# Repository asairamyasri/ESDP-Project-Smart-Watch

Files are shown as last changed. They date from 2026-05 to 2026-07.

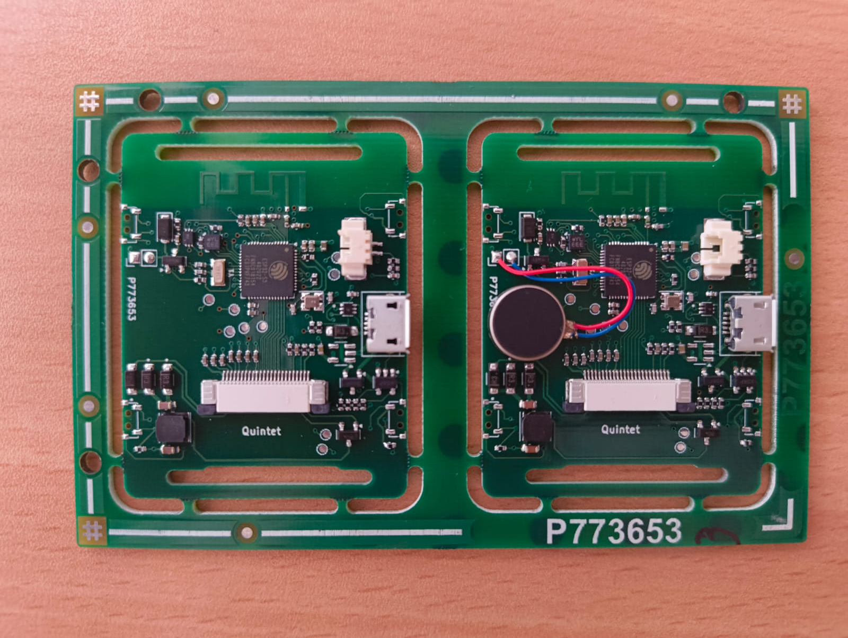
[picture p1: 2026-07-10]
Images/Fabricated_PCB.jpeg

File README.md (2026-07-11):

# Ultra-Low-Power ESP32 Smartwatch

## Overview
This project is an ESP32-based smartwatch using an E-Ink display for low-power wearable applications. 

## Features
- ESP32 microcontroller
- E-Ink display
- Low-power operation
- Real-time clock support
- Custom watch faces
- Battery-powered wearable system

## Team Members
- A Sai Ramya Sri (EE24BTECH11202)
- JLB Saraswathi (EE24BTECH11209)
- K Lakshmi Pranavi (EE24BTECH11210)
- Lakshitha Totakura (EE24BTECH11214)
- P Devi Amrutha (EE24BTECH11219)
## Project Structure
proposal/
bom/
hardware design/
software code/
current status/

## Hardware
The hardware section includes:
- Schematic design
- PCB layout
- Gerber files

## Software
The software section contains:
-GPIO Mapping: Hardware configuration for the ESP32-S3.
-Hardware tests: Firmware for component testing and bring-up.
-Driver Logic: Low-power E-Ink and battery management.
## Current Status

- [x] Create a Proposal
- [x] Prepare the BOM
- [x] Draw the schematic
- [x] PCB Layout
- [x] Generate Gerber Files
- [x] Order PCB on PCB Power
- [x] Design a case for the PCB
- [x] Develop Firmware
- [x] Receive PCB
- [ ] Firmware Integration
- [ ] Hardware Debugging if any

## Ongoing Work
Testing firmware on the PCB.

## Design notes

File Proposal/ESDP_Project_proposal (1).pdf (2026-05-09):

# Ultra-Low-Power ESP32 Smartwatch Project Proposal

### EE24BTECH11202 - Annapureddy Sai Ramyasri EE24BTECH11209 - J Laxmi Bhavani Saraswathi EE24BTECH11210 - Karri Lakshmi Pranavi EE24BTECH11214 - Lakshitha Totakura EE24BTECH11219 - Pothuri Devi Amrutha

### 1 Application / Problem Statement

With the rapid growth of wearable technology, smartwatches have become an essential tool for timekeeping, fitness tracking, and connectivity. However, most commercially available smartwatches suffer from a critical limitation: poor battery life. Frequent charging (often daily) significantly reduces usability and user convenience. Additionally, many smartwatches rely on power-hungry displays and continuously active wireless modules, making them inefficient for basic use cases such as timekeeping, alarms, and lightweight health monitoring.
There is a clear need for a low-power, cost-effective smartwatch that:
- Provides essential features like time display, stopwatch, and notifications
- Maximizes battery life (multi-day operation)
- Maintains readability in all lighting conditions
- Allows modular expansion for health monitoring

### 2 Proposed Solution

To address the above challenges, we propose the design and development of an Ultra-Low-Power Smartwatch based on the ESP32-S3 microcontroller.

### Core Architecture

The system is built around the ESP32-S3 dual-core microcontroller, which provides integrated Wi-Fi and Bluetooth Low Energy (BLE) capabilities for future wireless

synchronization and updates.

### Display System

A 1.54-inch E-Ink (GDEY0154D67) display with 200×200 resolution is used. Unlike traditional LCD/OLED displays, E-Ink:

- Consumes power only during refresh cycles
- Offers good sunlight readability
- Enables an always-on display with minimal power usage

### SPI Communication Interface

The communication between the ESP32-S3 and the E-Ink display is implemented using the Serial Peripheral Interface (SPI) protocol. The ESP32 acts as the master, while

the display functions as the slave device.
SPI enables fast and efficient transfer of command and display data using signals such as MOSI, SCLK, CS, and DC. Additional control lines like RST and BUSY ensure proper synchronization during display updates.
This interface is chosen for its high speed, low pin requirement, and suitability for display communication.

### User Interface

The smartwatch uses a non-touch physical interface consisting of four push buttons for navigation. A vibration motor is integrated to provide haptic feedback for alerts and user interactions.

### Power Management System

- Powered by a 3.7V Li-Po battery (200–500 mAh)
- Uses a low-dropout (LDO) regulator (NCP167AMX330TBG) to generate

stable 3.3V and 1.8V rails

- Includes a battery charging IC with constant-current (CC) and constant-voltage

(CV) charging

- Protection circuitry ensures safety against over-voltage, short-circuits, and deep

discharge

### Ultra-Low-Power Optimization

The ESP32 operates in deep sleep mode, reducing standby current to approximately 10–150 µA. The system wakes up only when necessary using:

- Button interrupts
- Motion detection via accelerometer

### Sensor Integration

- BMA423 Accelerometer: Used for motion detection, step counting, and wake-up

triggering

### Future Expansion

The I2C architecture allows easy integration of sensors like:

- MAX30102: Heart rate and SpO2 monitoring

### Debugging and Connectivity

A CP2102N/CP2104 USB-UART bridge is used for:

- Firmware uploading
- Serial debugging

An ESD protection circuit is included to safeguard the system from electrostatic discharge on USB lines.

### 3 Practical Feasibility and Cost Effectiveness

### Component Availability

All components used in the design are:

- Commercially available through distributors such as Digi-Key, Robu, Amazon.
- Widely used in embedded and IoT applications
- Supported by strong documentation and community resources

Key components such as ESP32-S3, E-Ink display modules, Li-Po batteries, and sensor ICs are readily accessible, ensuring smooth procurement and development.

### Cost Effectiveness

The design is optimized for affordability while maintaining performance. Key cost considerations:

- ESP32-S3 provides multiple functionalities (MCU + wireless), reducing component

count

- E-Ink display reduces long-term energy cost and battery size requirements
- Use of standard passive components and widely available ICs minimizes BOM cost

Based on the provided Bill of Materials (BOM), the estimated prototype cost remains

within a reasonable budget for academic and small-scale production purposes.

### Power Efficiency Advantage

The major advantage of this design is its extended battery life of 5–7 days, achieved through:

- Low-power display technology
- Deep sleep optimization
- Event-driven system wake-up

This makes the device significantly more efficient compared to conventional smartwatches.

### Implementation Feasibility

The project is highly feasible due to:

- Modular design architecture
- Availability of development tools for ESP32
- Simple PCB design with standard interfaces (I2C, UART, GPIO)

The system can be implemented, tested, and iteratively improved within a typical academic project timeline.
Total Component Cost : Rs.3,000
PCB Fabrication and Assembly : Rs.7,000 Total price : Rs.10,000

### 4 Conclusion

The proposed ultra-low-power smartwatch provides a practical and efficient solution to the limitations of existing wearable devices. By combining energy-efficient hardware, optimized power management, and scalable architecture, the design achieves a balance between functionality, cost, and battery life.

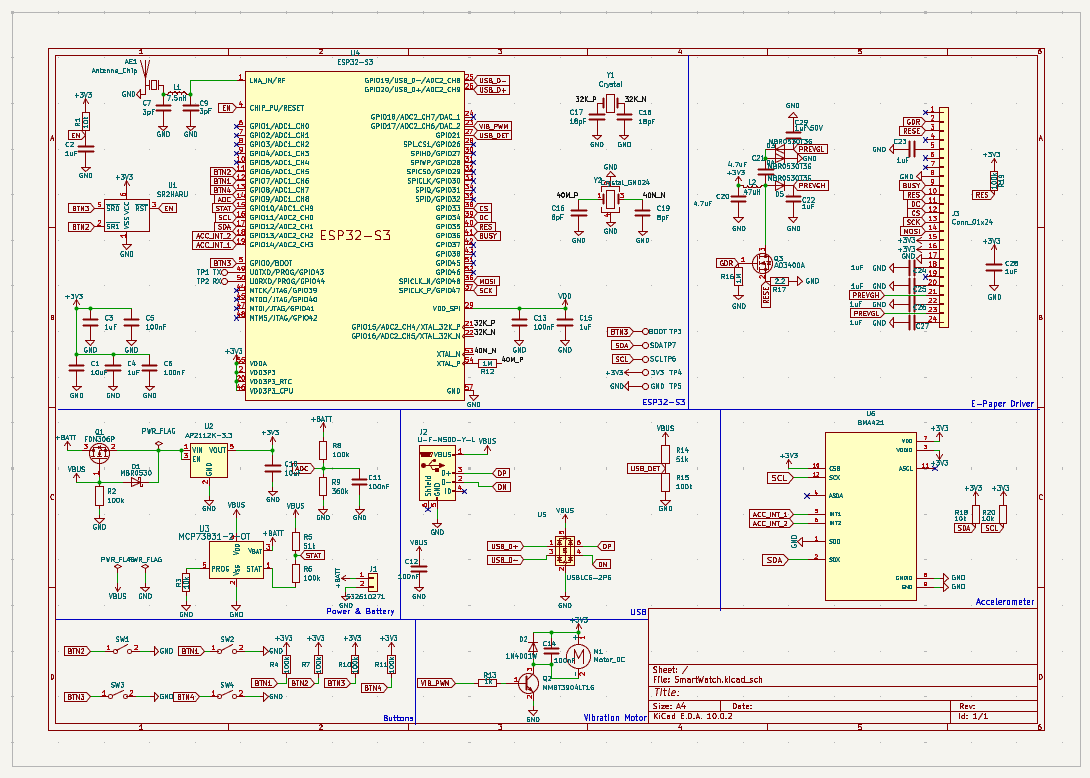
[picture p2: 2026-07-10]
Images/SmartWatch_Schematic.png

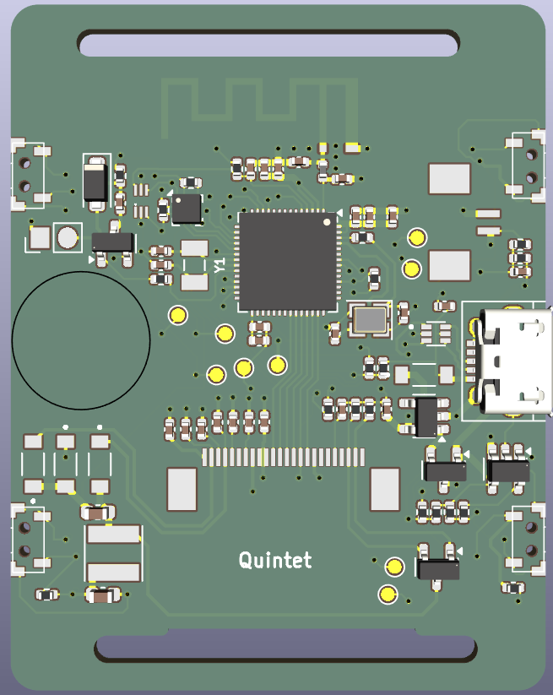
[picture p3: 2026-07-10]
Images/SmartWatch_PCBLayout_3D.png

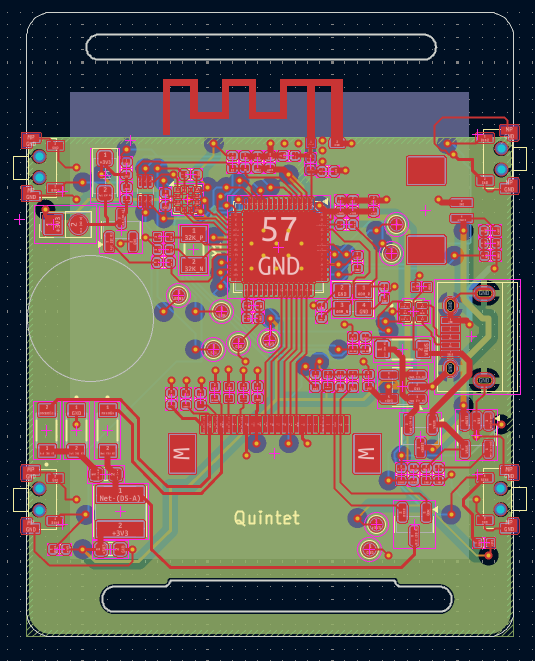
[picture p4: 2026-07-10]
Images/SmartWatch_PCBLayout_2D.png

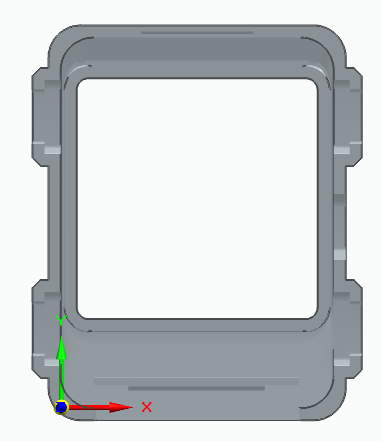
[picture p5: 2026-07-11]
Images/Top_Case.png

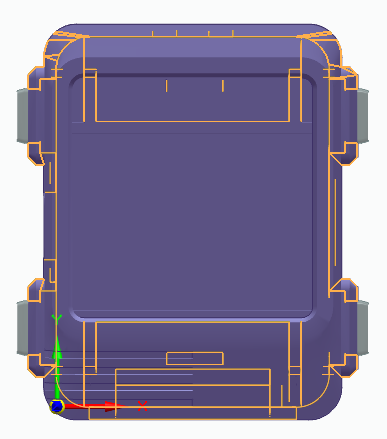
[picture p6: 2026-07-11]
Images/Final_Casing.png

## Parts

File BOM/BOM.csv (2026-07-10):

Id | Designator | Footprint | Quantity | Designation | MPN | Datasheet Link
1 | C22,C24,C26,C15,C4,C2,C3,C25,C23,C28,C27,C29 | C_0402_1005Metric | 12 | 1uF | C0402C105K4PACTU | https://www.mouser.in/datasheet/3/72/1/C0402C105K4PACTU.pdf
2 | R19,R4,R11,R2,R6,R15,R10,R7,R8 | R_0402_1005Metric | 9 | 100k | AC0402FR-07100KL | https://www.mouser.in/datasheet/3/508/1/PYU_AC_51_ROHS_L.pdf
3 | R1,R20,R3,R18 | R_0402_1005Metric | 4 | 10k | RC0402FR-0710KL | https://www.mouser.com/catalog/specsheets/YAGEO_PYu_RC_Group_51_RoHS_L_12.pdf
4 | Y1 | Crystal_SMD_2012-2Pin_2.0x1.2mm | 1 | Crystal | ABS07-32.768KHZ-T | https://www.mouser.in/datasheet/3/184/1/ABS07.pdf
5 | C6,C11,C5,C14,C12,C13 | C_0402_1005Metric | 6 | 100nF | 0402B104J250NT | https://www.mouser.in/datasheet/3/317/1/WTC_MLCC_General_Purpose.pdf
6 | C1,C10 | C_0402_1005Metric | 2 | 10uF | C0402B106M010T | https://www.holystonecaps.com/PDF/201612051328350.2017%20HCC%20Series.pdf
7 | Y2 | Crystal_SMD_2520-4Pin_2.5x2.0mm | 1 | Crystal_GND24 | XRCGB40M000F1S2FR0 | https://pim.murata.com/asset/pim4/ceramicResonatorCrystalUnit/SPEC_XRCGB40M000F1S2FR0_PDF_CERAMICRESONATORCRYSTALUNIT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
8 | SW3,SW4,SW1,SW2 | TS24CA | 4 | BTN3 | TS24CA 250gf 013 | https://www.lcsc.com/datasheet/C5373430.pdf
9 | R12,R16 | R_0402_1005Metric | 2 | 1M | RC0402JR-071ML | https://www.mouser.com/catalog/specsheets/YAGEO_PYu_RC_Group_51_RoHS_L_12.pdf
10 | C7,C9 | C_0402_1005Metric | 2 | 3pF | TCC0402COG3R0C500AT | https://www.lcsc.com/datasheet/C696883.pdf
11 | D1,D3,D5,D4 | DIO_MBR0530T3G | 4 | MBR0530T3G | MBR0530-TP | https://www.mouser.in/datasheet/3/225/1/MBR0520-MBR0580(SOD123).pdf
12 | R9 | R_0402_1005Metric | 1 | 360k | AC0402FR-07360KL | https://www.mouser.in/datasheet/3/508/1/PYU_AC_51_ROHS_L.pdf
13 | Q2 | SOT-23 | 1 | MMBT3904LT1G | MMBT3904LT1G | https://www.onsemi.com/pdf/datasheet/mmbt3904lt1-d.pdf
14 | J3 | 24_Pins_0.5mm_Pitch_ZIF_Connector_UP | 1 | Conn_01x24 | AFC07-S24ECA-00 | https://www.lcsc.com/datasheet/C262643.pdf
15 | J1 | 1.25T-2PWT (Molex 532610271) | 1 | 532610271 | 532610271 | https://www.molex.com/en-us/products/part-detail-pdf/532610271?display=pdf
16 | U2 | SOT-23-5 | 1 | AP2112K-3.3 | AP2112K-3.3TRG1 | https://www.mouser.in/datasheet/3/175/1/AP2112.pdf
17 | J2 | USB_Micro-B | 1 | U-F-M5DD-Y-L | U-F-M5DD-Y-L | https://www.lcsc.com/datasheet/C91146.pdf
18 | C21,C20 | C_0603_1608Metric | 2 | 4.7uF | GRM188Z71C475KE21D | https://pim.murata.com/asset/pim4/ceramicCapacitorSMD/GRM188Z71C475KE21-01A-EN_PDF_CERAMICCAPACITORSMD
19 | R14,R5 | R_0402_1005Metric | 2 | 51k | AC0402FR-0751KL | https://www.mouser.in/datasheet/3/508/1/PYU_AC_51_ROHS_L.pdf
20 | U5 | SOT-666 | 1 | USBLC6-2P6 | USBLC6-2P6 | https://www.st.com/resource/en/datasheet/usblc6-2.pdf
21 | C19,C16 | C_0402_1005Metric | 2 | 8pF | GRM1555C1H8R0CA01D | https://pim.murata.com/asset/pim4/ceramicCapacitorSMD/GRM1555C1H8R0CA01-01A-EN_PDF_CERAMICCAPACITORSMD
22 | U4 | QFN-56-1EP_7x7mm_P0.4mm_EP5.6x5.6mm | 1 | ESP32-S3 | ESP32-S3FN8 | https://documentation.espressif.com/esp32-s3_datasheet_en.pdf
23 | Q3 | SOT-23 | 1 | CJ3400A | CJ3400A | https://evelta.com/content/datasheets/217-CJ3400A.pdf
24 | D2 | D_SOD-123F | 1 | 1N4001W | 1N4001W | https://robu-prod-media.s3.ap-south-1.amazonaws.com/uploads/2025/02/C2936037.pdf
25 | L2 | L_Taiyo-Yuden_NR-40xx | 1 | 47uH | NR4018T470M | https://mm.digikey.com/Volume0/opasdata/d220001/medias/docus/610/NR4018T470M_SS.pdf
26 | C17,C18 | C_0402_1005Metric | 2 | 18pF | GRM1555C1H180JA01D | https://www.mouser.in/datasheet/3/76/1/GRM1555C1H180JA01-01A.pdf
27 | M1 | Motor_Header | 1 | Motor_DC | VC1020B111F | https://www.vybronics.com/coin-vibration-motors/with-brushes/v-c1020b111f
28 | L1 | L_0402_1005Metric | 1 | 7.5nH | LQG15HS7N5J02D | https://www.mouser.in/datasheet/3/76/2/JELF243B_0010.pdf
29 | U6 | LGA-12_2x2mm_P0.5mm | 1 | BMA421 | BMA421 | https://files.pine64.org/doc/datasheet/pinetime/BST-BMA421-FL000.pdf
30 | R13 | R_0402_1005Metric | 1 | 1k | AC0402FR-071KL | https://www.mouser.in/datasheet/3/508/1/PYU_AC_51_ROHS_L.pdf
31 | U1 | sr2haru | 1 | SR2HARU | SR2HARU | https://www.st.com/resource/en/datasheet/sr2.pdf
32 | U3 | SOT-23-5 | 1 | MCP73831-2-OT | MCP73831T-2ACI/OT | https://www.mouser.in/datasheet/3/282/1/MCP73831_Family_Data_Sheet_DS20001984H.pdf
33 | R17 | R_0402_1005Metric | 1 | 2.2 | WR04W2R20FTL | https://www.mouser.in/datasheet/3/317/1/ASC_WR.pdf
34 | Q1 | SOT-23 | 1 | FDN306P | FDN306P | https://www.onsemi.com/pdf/datasheet/fdn306p-d.pdf

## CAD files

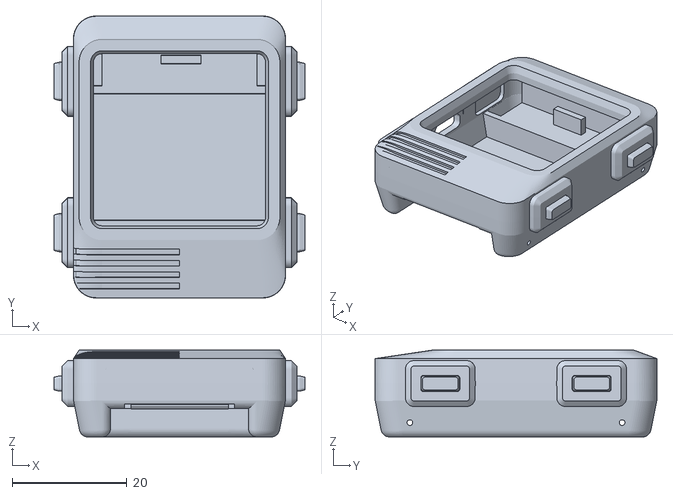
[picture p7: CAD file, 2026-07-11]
STL Files for Watch Case/Final.stl
43.7 x 49.2 x 15.2

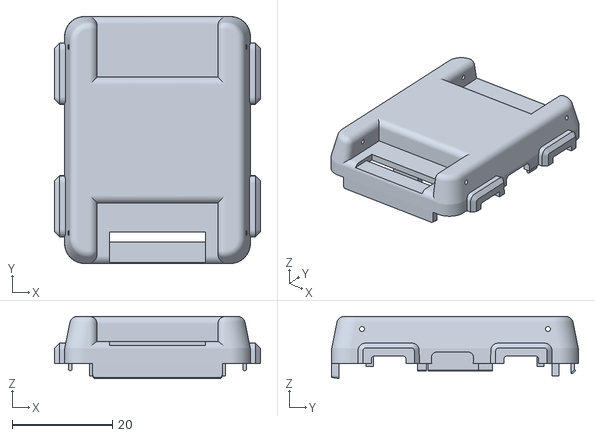
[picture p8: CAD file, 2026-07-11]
STL Files for Watch Case/Bottom.stl
41.0 x 49.2 x 12.4

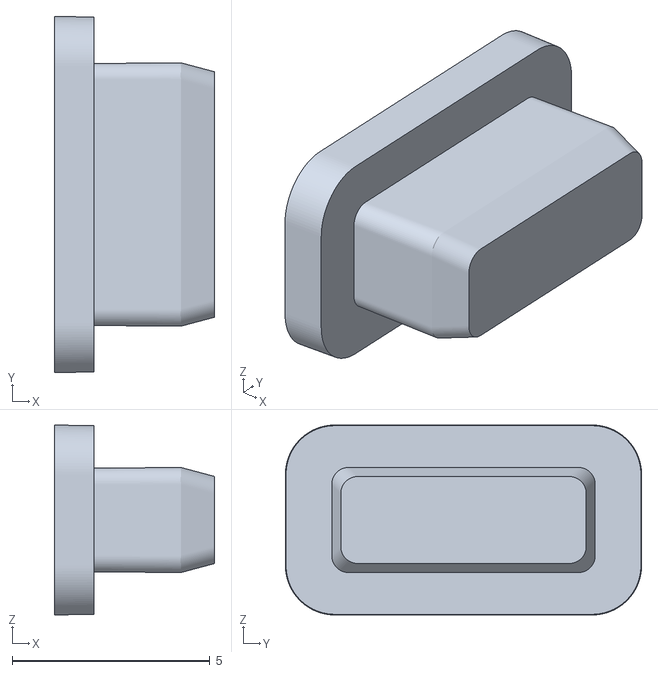
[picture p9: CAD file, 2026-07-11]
STL Files for Watch Case/Button.stl
4.05 x 9.00 x 4.80

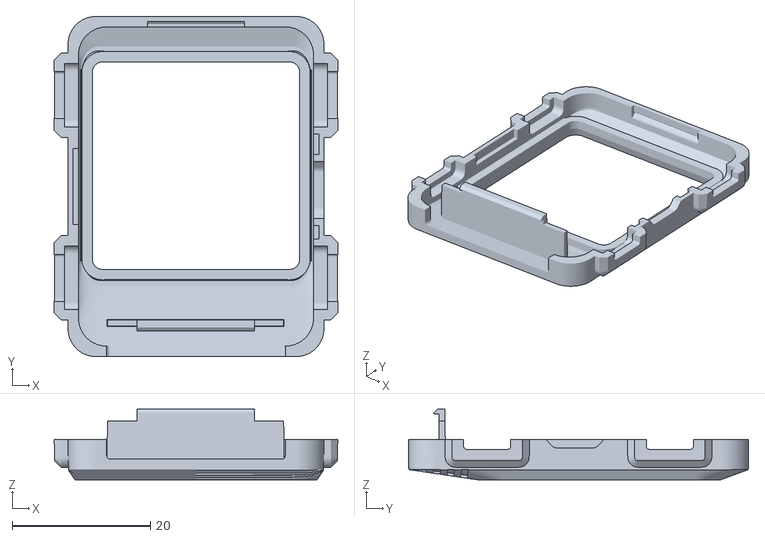
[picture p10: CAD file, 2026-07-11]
STL Files for Watch Case/Top.stl
41.0 x 49.2 x 10.3

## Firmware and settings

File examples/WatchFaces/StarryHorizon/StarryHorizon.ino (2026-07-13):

// STARRY HORIZON for Watchy by SQFMI
// Copyright 2021 Dan Delany dan.delany@gmail.com
// Released under free MIT License : https://github.com/dandelany/watchy-faces/blob/main/LICENSE

#include <Watchy.h> //include the Watchy library
#include <Fonts/FreeSansBold9pt7b.h> //include any fonts you want to use
#include "MadeSunflower39pt7b.h"
#include "stars.h"
#include "settings.h"

#define STAR_COUNT 900

const int horizonY = 150;
const int planetR = 650;

struct xyPoint {
  int x;
  int y;
};

//Star myStars[STAR_COUNT];
void initStars() {
  // The random star field is loaded from PROGMEM - see stars.h
  // this is the function that was used to generate the stars in stars.h
  // it does not run normally but can be used to re-generate stars with different parameters
  // tweak as needed, call this function in init, open serial monitor, and paste the results into stars.h
  srand(5287); // randomSeed() is not stable on ESP32, use srand
  printf("const Star STARS[] PROGMEM = {\n");
  for(int i = 0; i < STAR_COUNT; i++) {
    int starX = (rand() % 260) - 30;
    int starY = (rand() % 260) - 30;
    int radius = 0;
    if (i > STAR_COUNT * 0.99) radius = 2;
    else if (i > STAR_COUNT * 0.80) radius = 1;
    printf("  { %d, %d, %d },\n", starX, starY, radius);
//    myStars[i] = { starX, starY, radius };
  }
  printf("};\n");
}

struct xyPoint rotatePointAround(int x, int y, int ox, int oy, double angle) {
  // rotate X,Y point around given origin point by a given angle
  // based on https://gist.github.com/LyleScott/e36e08bfb23b1f87af68c9051f985302#file-rotate_2d_point-py-L38
  double qx = (double)ox + (cos(angle) * (double)(x - ox)) + (sin(angle) * (double)(y - oy));
  double qy = (double)oy + (-sin(angle) * (double)(x - ox)) + (cos(angle) * (double)(y - oy));
  struct xyPoint newPoint;
  newPoint.x = (int)qx;
  newPoint.y = (int)qy;
  return newPoint;
}

class StarryHorizon : public Watchy {
    public:
        StarryHorizon(const watchySettings& s) : Watchy(s) {
          // uncomment to re-generate stars
          // initStars();
        }
        void drawWatchFace(){
          display.fillScreen(GxEPD_BLACK);
          display.fillCircle(100, horizonY + planetR, planetR, GxEPD_WHITE);
          drawGrid();
          drawStars(STARS);
          drawTime();
          drawDate();
        }
        void drawGrid() {
          int prevY = horizonY;
          for(int i = 0; i < 40; i+= 1) {
            int y = prevY + int(abs(sin(double(i) / 10) * 10));
            if(y <= 200) {
              display.drawFastHLine(0, y, 200, GxEPD_BLACK);
            }
            prevY = y;
          }
          int vanishY = horizonY - 25;
          for (int x = -230; x < 430; x += 20) {
            display.drawLine(x, 200, 100, vanishY, GxEPD_BLACK);
          }
        }
        void drawStars(const Star stars[]) {
          // draw field of stars
          // rotate stars so that they make an entire revolution once per hour
          int minute = (int)currentTime.Minute;
          double minuteAngle = ((2.0 * M_PI) / 60.0) * (double)minute;
//          printf("Minute %d, angle %f\n", (int)currentTime.Minute, minuteAngle);

          for(int starI = 0; starI < STAR_COUNT; starI++) {
            int starX = stars[starI].x;
            int starY = stars[starI].y;
            int starR = stars[starI].r;

            struct xyPoint rotated = rotatePointAround(starX, starY, 100, 100, minuteAngle);
            if(rotated.x < 0 || rotated.y < 0 || rotated.x > 200 || rotated.y > horizonY) {
              continue;
            }
            if(starR == 0) {
              display.drawPixel(rotated.x, rotated.y, GxEPD_WHITE);
            } else {
              display.fillCircle(rotated.x, rotated.y, starR, GxEPD_WHITE);
            }
          }
        }
        void drawTime() {
          display.setFont(&MADE_Sunflower_PERSONAL_USE39pt7b);
          display.setTextColor(GxEPD_WHITE);
          display.setTextWrap(false);
          char* timeStr;
          asprintf(&timeStr, "%d:%02d", currentTime.Hour, currentTime.Minute);
          drawCenteredString(timeStr, 100, 115, false);
          free(timeStr);
        }

        void drawDate() {
          String monthStr = monthShortStr(currentTime.Month);
          String dayOfWeek = dayShortStr(currentTime.Wday);
          display.setFont(&FreeSansBold9pt7b);
          display.setTextColor(GxEPD_WHITE);
          display.setTextWrap(false);
          char* dateStr;
          asprintf(&dateStr, "%s %s %d", dayOfWeek.c_str(), monthStr.c_str(), currentTime.Day);
          drawCenteredString(dateStr, 100, 140, true);
          free(dateStr);
        }

        void drawCenteredString(const String &str, int x, int y, bool drawBg) {
          int16_t x1, y1;
          uint16_t w, h;

          display.getTextBounds(str, x, y, &x1, &y1, &w, &h);
//          printf("bounds: %d x %d y, %d x1 %d y1, %d w, %d h\n", 0, 100, x1, y1, w, h);
          display.setCursor(x - w / 2, y);
          if(drawBg) {
            int padY = 3;
            int padX = 10;
            display.fillRect(x - (w / 2 + padX), y - (h + padY), w + padX*2, h + padY*2, GxEPD_BLACK);
          }
          // uncomment to draw bounding box
//          display.drawRect(x - w / 2, y - h, w, h, GxEPD_WHITE);
          display.print(str);
        }
};

StarryHorizon face(settings); //instantiate watchface

void setup() {
  face.init(); //call init in setup
}

void loop() {
  // this should never run, Watchy deep sleeps after init();
}

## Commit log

2026-05-09 Create prop
2026-05-09 Create bom
2026-05-09 Add initial hardware test for motor and button
2026-05-09 Implement Display Driver functionality
2026-05-09 Update software section in README.md
    Added GPIO Mapping, Diagnostic Suite, and Driver Logic to the software section.
2026-07-10 Create Gerber Files
